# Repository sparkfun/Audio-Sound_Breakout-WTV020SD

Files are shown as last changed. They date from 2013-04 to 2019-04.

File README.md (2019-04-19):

**NOTE:** *This product has been retired from our catalog. For alternatives, try looking at the following products from the [Audio boards](https://www.sparkfun.com/categories/343):*

* [Little Soundie Audio Player](https://www.sparkfun.com/products/14006)
* [Qwiic MP3 Trigger](https://www.sparkfun.com/products/15165)

*If you are looking for more up-to-date info, please check out some of these resources to see how other users are still hacking and improving on this product.*

* *[SparkFun Forum](https://forum.sparkfun.com/)*
* *[IRC Channel](https://www.sparkfun.com/news/263)*

Audio-Sound Breakout
====================

[Audio-Sound Breakout  
*Audio-Sound Breakout (WIG-11125)*](https://www.sparkfun.com/products/11125)

* Firmware was compiled in Arduino 1.0.3.
* Hardware was developed in EAGLE 6.3.0.
* Fritzing part created under 0.7.12.

License Information
-------------------
The hardware design is released under [CC-SA v3 license](http://creativecommons.org/licenses/by-sa/3.0/us/).

The firmware is released under a modified beerware license, allowing for the purchase of any libation, alcoholic or non.

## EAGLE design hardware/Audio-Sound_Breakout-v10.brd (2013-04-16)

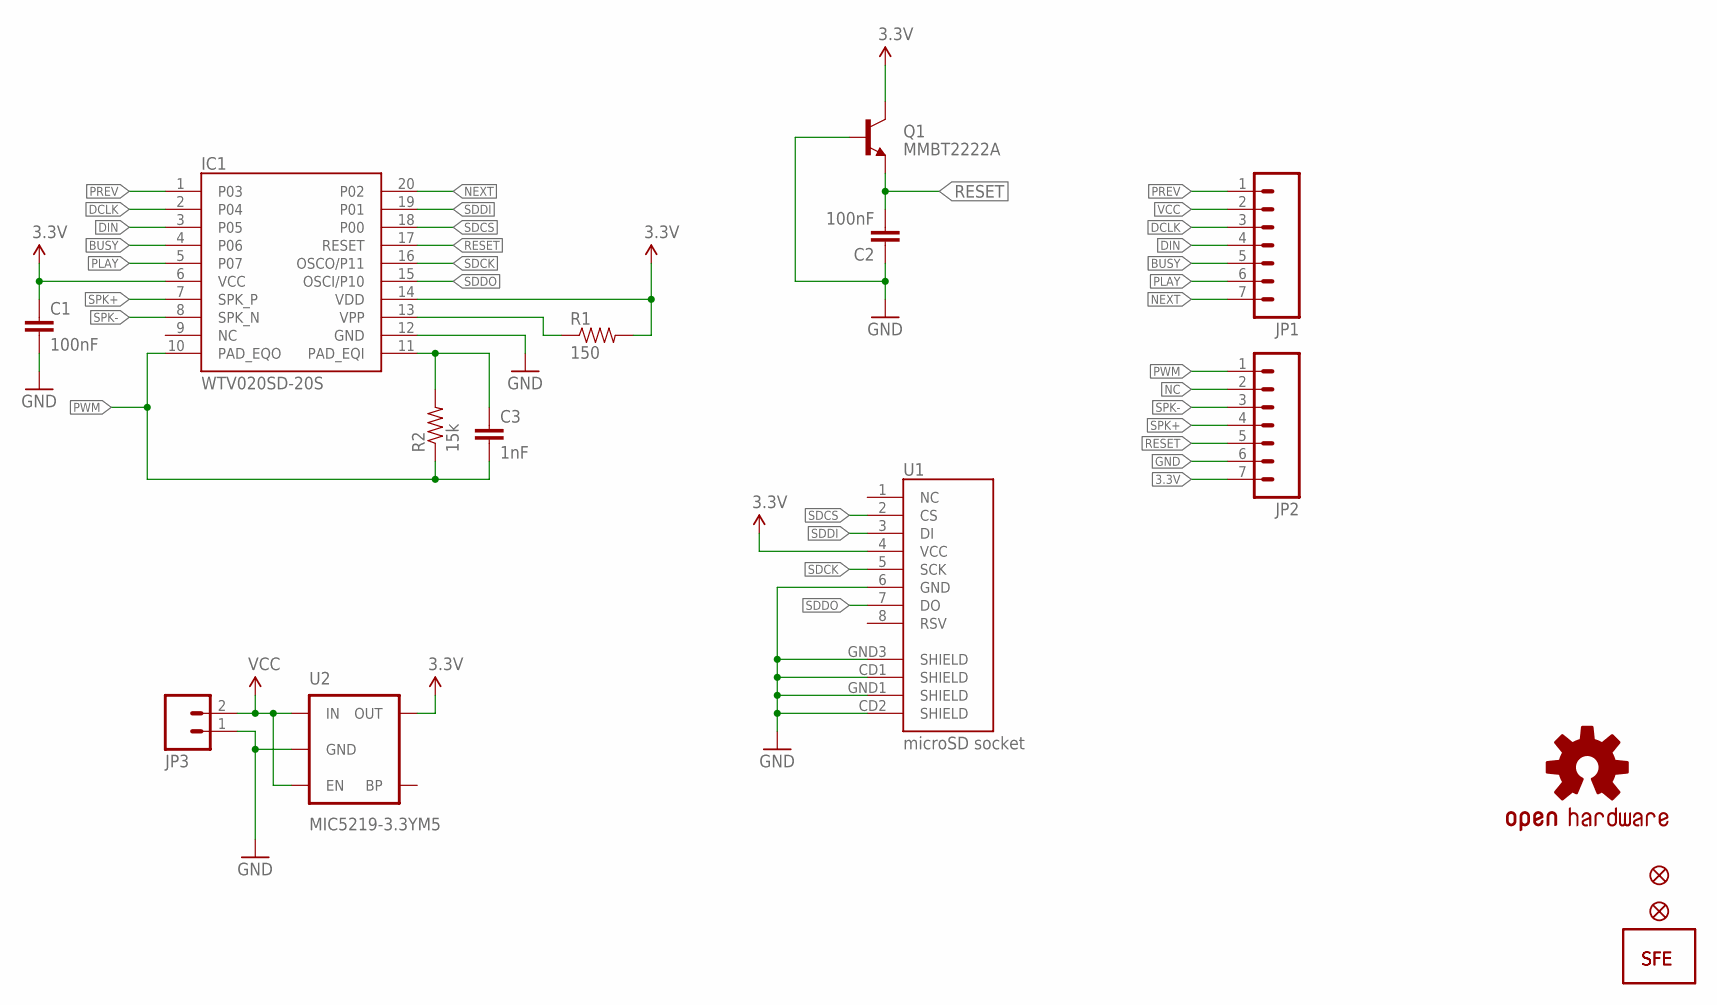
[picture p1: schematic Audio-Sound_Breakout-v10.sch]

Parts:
C1, C2: 100nF; 0402-CAP
C3: 1nF; 0402-CAP
IC1: WTV020SD-20S; SSOP_20
JP1, JP2: M07; 1X07
JP3: M02-JST-2MM-SMT; JST-2-SMD
JP4: LOGO-SFENW2; SFE-NEW-WEB
JP5: LOGO-SFENEW; SFE-NEW-WEBLOGO
JP6, JP7: FIDUCIALUFIDUCIAL; MICRO-FIDUCIAL
Q1: MMBT2222A; SOT23
R1: 150; 0402-RES
R2: 15k; 0402-RES
U1: microSD socket; MICRO-SD-SOCKET-PP
U2: MIC5219-3.3YM5; SOT23-5
U$1: OSHW-LOGOS; OSHW-LOGO-S

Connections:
3.3V: C1.1, IC1.6 (VCC), IC1.14 (VDD), JP2.7, Q1.3 (C), R1.2, U1.4 (VCC), U2.5 (OUT)
BUSY: IC1.4 (P06), JP1.5
DCLK: IC1.2 (P04), JP1.3
DIN: IC1.3 (P05), JP1.4
GND: C1.2, C2.1, IC1.12 (GND), JP2.6, JP3.1 (2), Q1.1 (B), U1.6 (GND), U1.CD1 (SHIELD), U1.CD2 (SHIELD), U1.GND1 (SHIELD), U1.GND3 (SHIELD), U2.2 (GND)
unnamed: IC1.13 (VPP), R1.1
unnamed: C3.1, IC1.11 (PAD_EQI), R2.2
NC: JP2.2
NEXT: IC1.20 (P02), JP1.7
PLAY: IC1.5 (P07), JP1.6
PREV: IC1.1 (P03), JP1.1
PWM: C3.2, IC1.10 (PAD_EQO), JP2.1, R2.1
RESET: C2.2, IC1.17 (RESET), JP2.5, Q1.2 (E)
SDCK: IC1.16 (OSCO/P11), U1.5 (SCK)
SDCS: IC1.18 (P00), U1.2 (CS)
SDDI: IC1.19 (P01), U1.3 (DI)
SDDO: IC1.15 (OSCI/P10), U1.7 (DO)
SPK+: IC1.7 (SPK_P), JP2.4
SPK-: IC1.8 (SPK_N), JP2.3
VCC: JP1.2, JP3.2 (1), U2.1 (IN), U2.3 (EN)

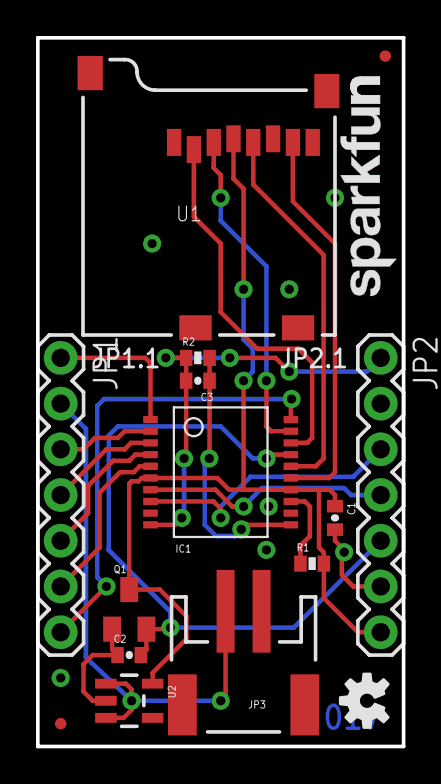
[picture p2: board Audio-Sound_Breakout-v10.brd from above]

Board: 2 copper layers, 20.3 x 39.4 mm, 17 parts (1 on the bottom side), 19 nets.

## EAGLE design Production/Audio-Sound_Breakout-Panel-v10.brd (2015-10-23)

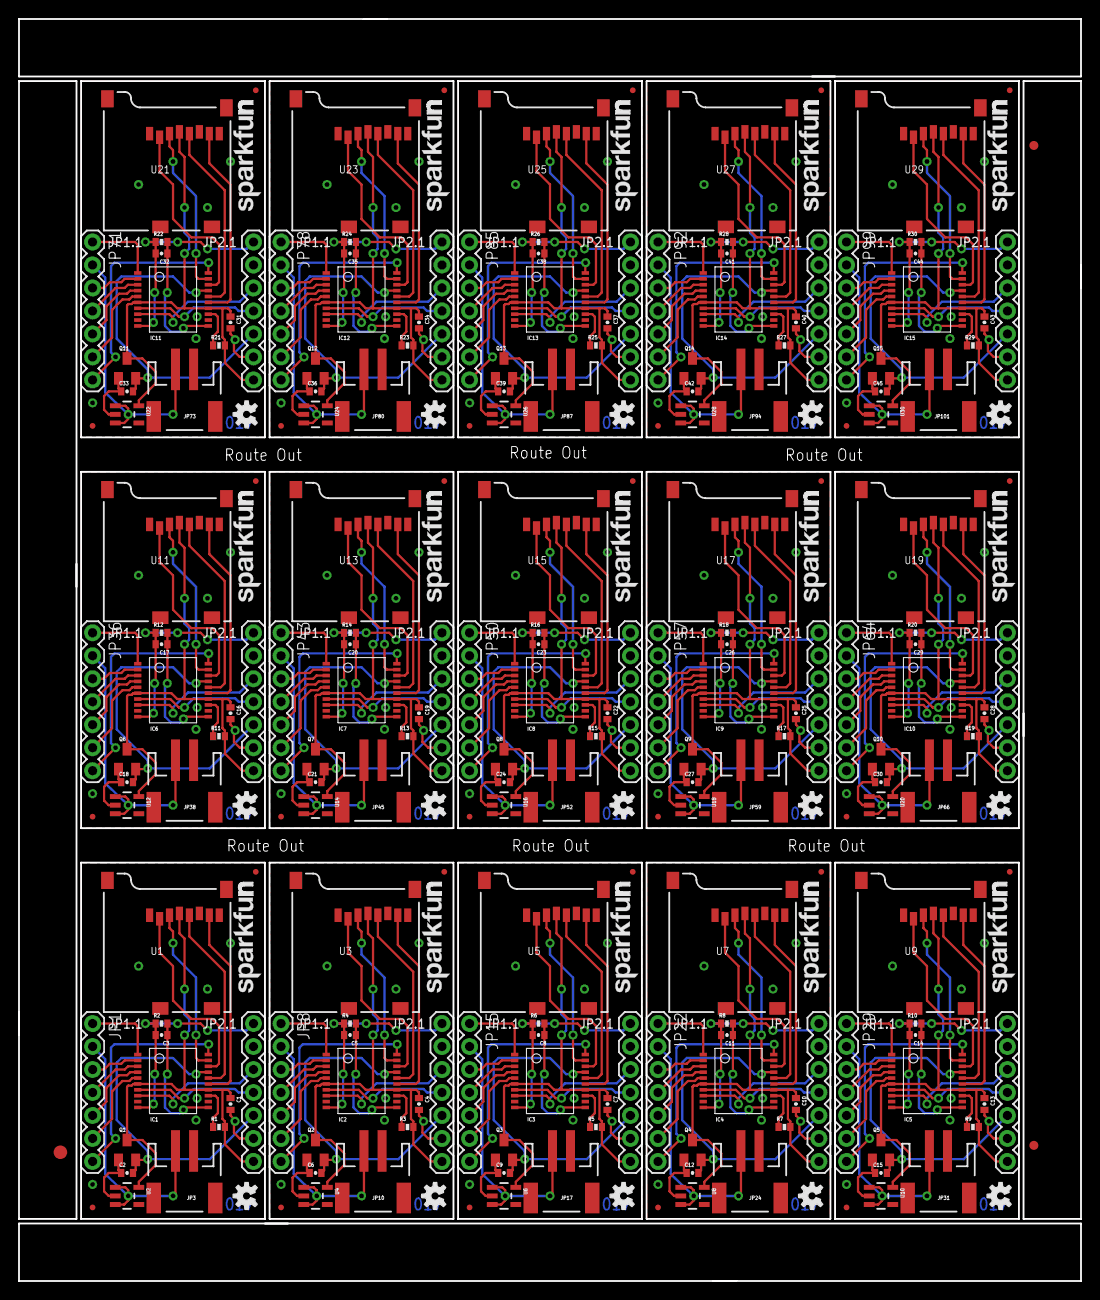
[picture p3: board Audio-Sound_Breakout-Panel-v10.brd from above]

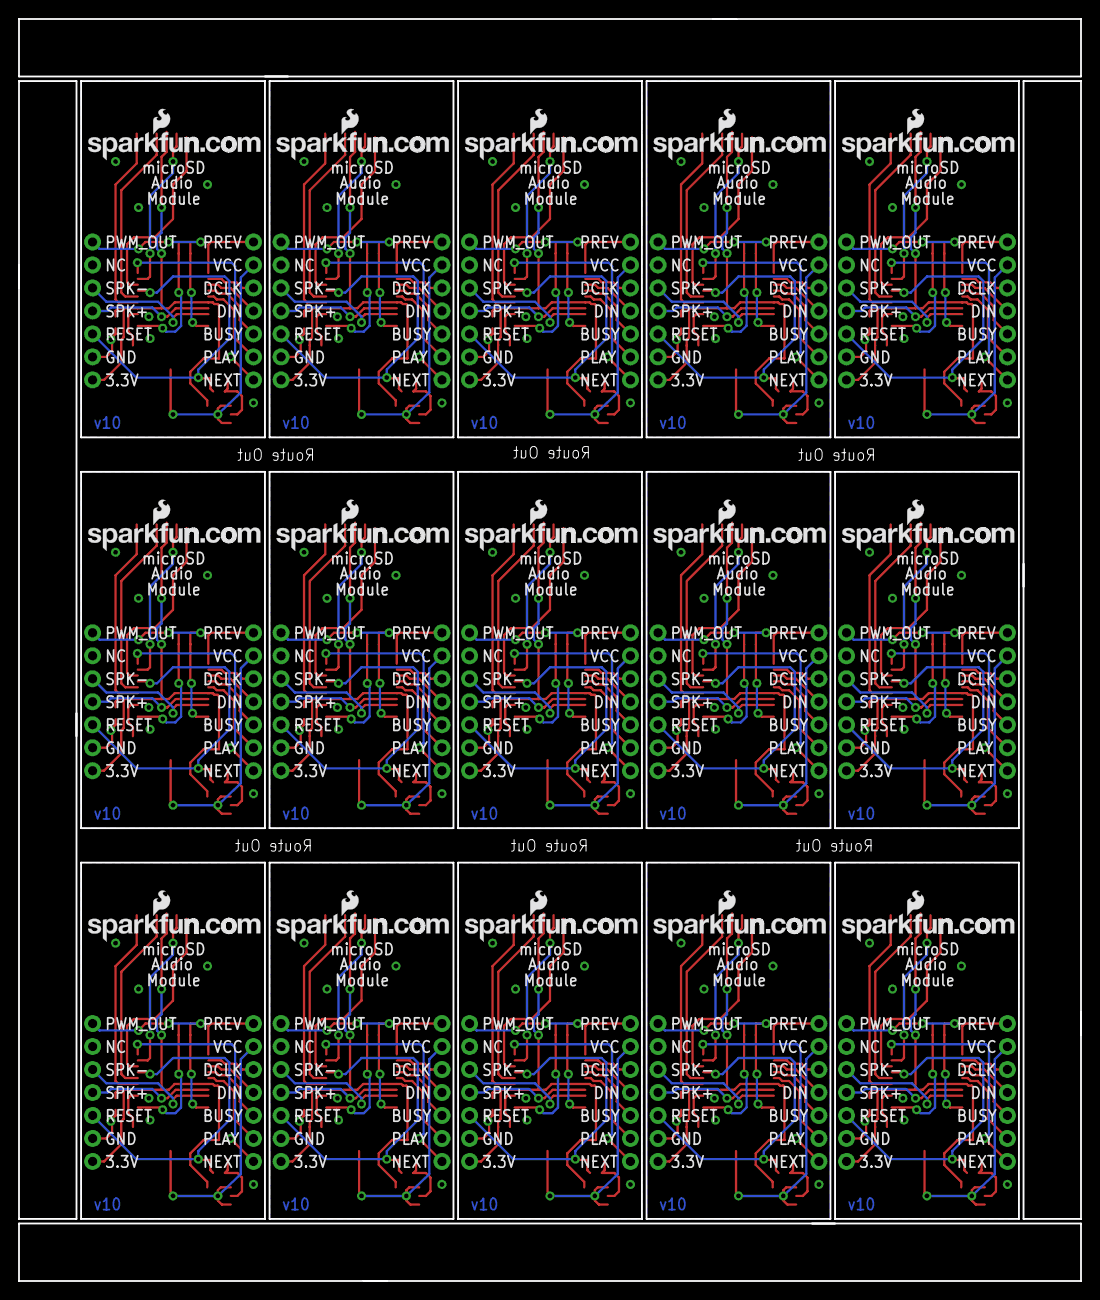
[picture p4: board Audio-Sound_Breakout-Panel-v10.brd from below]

Board: 2 copper layers, 117.3 x 139.4 mm, 258 parts (15 on the bottom side), 285 nets.

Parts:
C1, C2, C4, C6, C7, C9, C10, C12, C13, C15, C16, C18, C19, C21, C22, C24, C25, C27, C28, C30, C31, C33, C34, C36, C37, C39, C40, C42, C43, C45: 100nF; 0402-CAP
C3, C5, C8, C11, C14, C17, C20, C23, C26, C29, C32, C35, C38, C41, C44: 1nF; 0402-CAP
E$1: FIDUCIAL-1.5X3
E$7, E$8: FIDUCIAL-1X2
IC1, IC2, IC3, IC4, IC5, IC6, IC7, IC8, IC9, IC10, IC11, IC12, IC13, IC14, IC15: WTV020SD-20S; SSOP_20
JP1, JP2, JP8, JP9, JP15, JP16, JP22, JP23, JP29, JP30, JP36, JP37, JP43, JP44, JP50, JP51, JP57, JP58, JP64, JP65, JP71, JP72, JP78, JP79, JP85, JP86, JP92, JP93, JP99, JP100: 1X07
JP3, JP10, JP17, JP24, JP31, JP38, JP45, JP52, JP59, JP66, JP73, JP80, JP87, JP94, JP101: JST-2-SMD
JP4, JP11, JP18, JP25, JP32, JP39, JP46, JP53, JP60, JP67, JP74, JP81, JP88, JP95, JP102: LOGO-SFENW2; SFE-NEW-WEB
JP5, JP12, JP19, JP26, JP33, JP40, JP47, JP54, JP61, JP68, JP75, JP82, JP89, JP96, JP103: LOGO-SFENEW; SFE-NEW-WEBLOGO
JP6, JP7, JP13, JP14, JP20, JP21, JP27, JP28, JP34, JP35, JP41, JP42, JP48, JP49, JP55, JP56, JP62, JP63, JP69, JP70, JP76, JP77, JP83, JP84, JP90, JP91, JP97, JP98, JP104, JP105: FIDUCIALUFIDUCIAL; MICRO-FIDUCIAL
Q1, Q2, Q3, Q4, Q5, Q6, Q7, Q8, Q9, Q10, Q11, Q12, Q13, Q14, Q15: MMBT2222A; SOT23
R1, R3, R5, R7, R9, R11, R13, R15, R17, R19, R21, R23, R25, R27, R29: 150; 0402-RES
R2, R4, R6, R8, R10, R12, R14, R16, R18, R20, R22, R24, R26, R28, R30: 15k; 0402-RES
U1, U3, U5, U7, U9, U11, U13, U15, U17, U19, U21, U23, U25, U27, U29: microSD socket; MICRO-SD-SOCKET-PP
U2, U4, U6, U8, U10, U12, U14, U16, U18, U20, U22, U24, U26, U28, U30: MIC5219-3.3YM5; SOT23-5
U$1, U$2, U$3, U$4, U$5, U$6, U$7, U$8, U$9, U$10, U$11, U$12, U$13, U$14, U$15: OSHW-LOGOS; OSHW-LOGO-S

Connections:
3.3V: C1.1, IC1.6, IC1.14, JP2.7, Q1.3, R1.2, U1.4, U2.5
3.3V1: C4.1, IC2.6, IC2.14, JP9.7, Q2.3, R3.2, U3.4, U4.5
3.3V2: C7.1, IC3.6, IC3.14, JP16.7, Q3.3, R5.2, U5.4, U6.5
3.3V3: C10.1, IC4.6, IC4.14, JP23.7, Q4.3, R7.2, U7.4, U8.5
3.3V4: C13.1, IC5.6, IC5.14, JP30.7, Q5.3, R9.2, U9.4, U10.5
3.3V5: C16.1, IC6.6, IC6.14, JP37.7, Q6.3, R11.2, U11.4, U12.5
3.3V6: C19.1, IC7.6, IC7.14, JP44.7, Q7.3, R13.2, U13.4, U14.5
3.3V7: C22.1, IC8.6, IC8.14, JP51.7, Q8.3, R15.2, U15.4, U16.5
3.3V8: C25.1, IC9.6, IC9.14, JP58.7, Q9.3, R17.2, U17.4, U18.5
3.3V9: C28.1, IC10.6, IC10.14, JP65.7, Q10.3, R19.2, U19.4, U20.5
3.3V10: C31.1, IC11.6, IC11.14, JP72.7, Q11.3, R21.2, U21.4, U22.5
3.3V11: C34.1, IC12.6, IC12.14, JP79.7, Q12.3, R23.2, U23.4, U24.5
3.3V12: C37.1, IC13.6, IC13.14, JP86.7, Q13.3, R25.2, U25.4, U26.5
3.3V13: C40.1, IC14.6, IC14.14, JP93.7, Q14.3, R27.2, U27.4, U28.5
3.3V14: C43.1, IC15.6, IC15.14, JP100.7, Q15.3, R29.2, U29.4, U30.5
BUSY: IC1.4, JP1.5
BUSY1: IC2.4, JP8.5
BUSY2: IC3.4, JP15.5
BUSY3: IC4.4, JP22.5
BUSY4: IC5.4, JP29.5
BUSY5: IC6.4, JP36.5
BUSY6: IC7.4, JP43.5
BUSY7: IC8.4, JP50.5
BUSY8: IC9.4, JP57.5
BUSY9: IC10.4, JP64.5
BUSY10: IC11.4, JP71.5
BUSY11: IC12.4, JP78.5
BUSY12: IC13.4, JP85.5
BUSY13: IC14.4, JP92.5
BUSY14: IC15.4, JP99.5
DCLK: IC1.2, JP1.3
DCLK1: IC2.2, JP8.3
DCLK2: IC3.2, JP15.3
DCLK3: IC4.2, JP22.3
DCLK4: IC5.2, JP29.3
DCLK5: IC6.2, JP36.3
DCLK6: IC7.2, JP43.3
DCLK7: IC8.2, JP50.3
DCLK8: IC9.2, JP57.3
DCLK9: IC10.2, JP64.3
DCLK10: IC11.2, JP71.3
DCLK11: IC12.2, JP78.3
DCLK12: IC13.2, JP85.3
DCLK13: IC14.2, JP92.3
DCLK14: IC15.2, JP99.3
DIN: IC1.3, JP1.4
DIN1: IC2.3, JP8.4
DIN2: IC3.3, JP15.4
DIN3: IC4.3, JP22.4
DIN4: IC5.3, JP29.4
DIN5: IC6.3, JP36.4
DIN6: IC7.3, JP43.4
DIN7: IC8.3, JP50.4
DIN8: IC9.3, JP57.4
DIN9: IC10.3, JP64.4
DIN10: IC11.3, JP71.4
DIN11: IC12.3, JP78.4
DIN12: IC13.3, JP85.4
DIN13: IC14.3, JP92.4
DIN14: IC15.3, JP99.4
GND: C1.2, C2.1, IC1.12, JP2.6, JP3.1, Q1.1, U1.6, U1.CD1, U1.CD2, U1.GND1, U1.GND3, U2.2
GND1: C4.2, C6.1, IC2.12, JP9.6, JP10.1, Q2.1, U3.6, U3.CD1, U3.CD2, U3.GND1, U3.GND3, U4.2
GND2: C7.2, C9.1, IC3.12, JP16.6, JP17.1, Q3.1, U5.6, U5.CD1, U5.CD2, U5.GND1, U5.GND3, U6.2
GND3: C10.2, C12.1, IC4.12, JP23.6, JP24.1, Q4.1, U7.6, U7.CD1, U7.CD2, U7.GND1, U7.GND3, U8.2
GND4: C13.2, C15.1, IC5.12, JP30.6, JP31.1, Q5.1, U9.6, U9.CD1, U9.CD2, U9.GND1, U9.GND3, U10.2
GND5: C16.2, C18.1, IC6.12, JP37.6, JP38.1, Q6.1, U11.6, U11.CD1, U11.CD2, U11.GND1, U11.GND3, U12.2
GND6: C19.2, C21.1, IC7.12, JP44.6, JP45.1, Q7.1, U13.6, U13.CD1, U13.CD2, U13.GND1, U13.GND3, U14.2
GND7: C22.2, C24.1, IC8.12, JP51.6, JP52.1, Q8.1, U15.6, U15.CD1, U15.CD2, U15.GND1, U15.GND3, U16.2
GND8: C25.2, C27.1, IC9.12, JP58.6, JP59.1, Q9.1, U17.6, U17.CD1, U17.CD2, U17.GND1, U17.GND3, U18.2
GND9: C28.2, C30.1, IC10.12, JP65.6, JP66.1, Q10.1, U19.6, U19.CD1, U19.CD2, U19.GND1, U19.GND3, U20.2
GND10: C31.2, C33.1, IC11.12, JP72.6, JP73.1, Q11.1, U21.6, U21.CD1, U21.CD2, U21.GND1, U21.GND3, U22.2
GND11: C34.2, C36.1, IC12.12, JP79.6, JP80.1, Q12.1, U23.6, U23.CD1, U23.CD2, U23.GND1, U23.GND3, U24.2
GND12: C37.2, C39.1, IC13.12, JP86.6, JP87.1, Q13.1, U25.6, U25.CD1, U25.CD2, U25.GND1, U25.GND3, U26.2
GND13: C40.2, C42.1, IC14.12, JP93.6, JP94.1, Q14.1, U27.6, U27.CD1, U27.CD2, U27.GND1, U27.GND3, U28.2
GND14: C43.2, C45.1, IC15.12, JP100.6, JP101.1, Q15.1, U29.6, U29.CD1, U29.CD2, U29.GND1, U29.GND3, U30.2
unnamed: IC1.13, R1.1
unnamed: C3.1, IC1.11, R2.2
unnamed: IC2.13, R3.1
unnamed: C5.1, IC2.11, R4.2
unnamed: IC3.13, R5.1
unnamed: C8.1, IC3.11, R6.2
unnamed: IC4.13, R7.1
unnamed: C11.1, IC4.11, R8.2
unnamed: IC5.13, R9.1
unnamed: C14.1, IC5.11, R10.2
unnamed: IC6.13, R11.1
unnamed: C17.1, IC6.11, R12.2
unnamed: IC7.13, R13.1
unnamed: C20.1, IC7.11, R14.2
unnamed: IC8.13, R15.1
unnamed: C23.1, IC8.11, R16.2
unnamed: IC9.13, R17.1
unnamed: C26.1, IC9.11, R18.2
unnamed: IC10.13, R19.1
unnamed: C29.1, IC10.11, R20.2
unnamed: IC11.13, R21.1
unnamed: C32.1, IC11.11, R22.2
unnamed: IC12.13, R23.1
unnamed: C35.1, IC12.11, R24.2
unnamed: IC13.13, R25.1
unnamed: C38.1, IC13.11, R26.2
unnamed: IC14.13, R27.1
unnamed: C41.1, IC14.11, R28.2
unnamed: IC15.13, R29.1
unnamed: C44.1, IC15.11, R30.2
NEXT: IC1.20, JP1.7
NEXT1: IC2.20, JP8.7
NEXT2: IC3.20, JP15.7
NEXT3: IC4.20, JP22.7
NEXT4: IC5.20, JP29.7
NEXT5: IC6.20, JP36.7
NEXT6: IC7.20, JP43.7
NEXT7: IC8.20, JP50.7
NEXT8: IC9.20, JP57.7
NEXT9: IC10.20, JP64.7
NEXT10: IC11.20, JP71.7
NEXT11: IC12.20, JP78.7
NEXT12: IC13.20, JP85.7
NEXT13: IC14.20, JP92.7
NEXT14: IC15.20, JP99.7
PLAY: IC1.5, JP1.6
PLAY1: IC2.5, JP8.6
PLAY2: IC3.5, JP15.6
PLAY3: IC4.5, JP22.6
PLAY4: IC5.5, JP29.6
PLAY5: IC6.5, JP36.6
PLAY6: IC7.5, JP43.6
PLAY7: IC8.5, JP50.6
PLAY8: IC9.5, JP57.6
PLAY9: IC10.5, JP64.6
PLAY10: IC11.5, JP71.6
PLAY11: IC12.5, JP78.6
PLAY12: IC13.5, JP85.6
PLAY13: IC14.5, JP92.6
PLAY14: IC15.5, JP99.6
PREV: IC1.1, JP1.1
PREV1: IC2.1, JP8.1
PREV2: IC3.1, JP15.1
PREV3: IC4.1, JP22.1
PREV4: IC5.1, JP29.1
PREV5: IC6.1, JP36.1
PREV6: IC7.1, JP43.1
PREV7: IC8.1, JP50.1
PREV8: IC9.1, JP57.1
PREV9: IC10.1, JP64.1
PREV10: IC11.1, JP71.1
PREV11: IC12.1, JP78.1
PREV12: IC13.1, JP85.1
PREV13: IC14.1, JP92.1
PREV14: IC15.1, JP99.1
PWM: C3.2, IC1.10, JP2.1, R2.1
PWM1: C5.2, IC2.10, JP9.1, R4.1
PWM2: C8.2, IC3.10, JP16.1, R6.1
PWM3: C11.2, IC4.10, JP23.1, R8.1
PWM4: C14.2, IC5.10, JP30.1, R10.1
PWM5: C17.2, IC6.10, JP37.1, R12.1
PWM6: C20.2, IC7.10, JP44.1, R14.1
PWM7: C23.2, IC8.10, JP51.1, R16.1
PWM8: C26.2, IC9.10, JP58.1, R18.1
PWM9: C29.2, IC10.10, JP65.1, R20.1
PWM10: C32.2, IC11.10, JP72.1, R22.1
PWM11: C35.2, IC12.10, JP79.1, R24.1
PWM12: C38.2, IC13.10, JP86.1, R26.1
PWM13: C41.2, IC14.10, JP93.1, R28.1
PWM14: C44.2, IC15.10, JP100.1, R30.1
RESET: C2.2, IC1.17, JP2.5, Q1.2
RESET1: C6.2, IC2.17, JP9.5, Q2.2
RESET2: C9.2, IC3.17, JP16.5, Q3.2
RESET3: C12.2, IC4.17, JP23.5, Q4.2
RESET4: C15.2, IC5.17, JP30.5, Q5.2
RESET5: C18.2, IC6.17, JP37.5, Q6.2
RESET6: C21.2, IC7.17, JP44.5, Q7.2
RESET7: C24.2, IC8.17, JP51.5, Q8.2
RESET8: C27.2, IC9.17, JP58.5, Q9.2
RESET9: C30.2, IC10.17, JP65.5, Q10.2
RESET10: C33.2, IC11.17, JP72.5, Q11.2
RESET11: C36.2, IC12.17, JP79.5, Q12.2
RESET12: C39.2, IC13.17, JP86.5, Q13.2
RESET13: C42.2, IC14.17, JP93.5, Q14.2
RESET14: C45.2, IC15.17, JP100.5, Q15.2
SDCK: IC1.16, U1.5
SDCK1: IC2.16, U3.5
SDCK2: IC3.16, U5.5
SDCK3: IC4.16, U7.5
SDCK4: IC5.16, U9.5
SDCK5: IC6.16, U11.5
SDCK6: IC7.16, U13.5
SDCK7: IC8.16, U15.5
SDCK8: IC9.16, U17.5
SDCK9: IC10.16, U19.5
SDCK10: IC11.16, U21.5
SDCK11: IC12.16, U23.5
SDCK12: IC13.16, U25.5
SDCK13: IC14.16, U27.5
SDCK14: IC15.16, U29.5
SDCS: IC1.18, U1.2
SDCS1: IC2.18, U3.2
SDCS2: IC3.18, U5.2
SDCS3: IC4.18, U7.2
SDCS4: IC5.18, U9.2
SDCS5: IC6.18, U11.2
SDCS6: IC7.18, U13.2
SDCS7: IC8.18, U15.2
SDCS8: IC9.18, U17.2
SDCS9: IC10.18, U19.2
SDCS10: IC11.18, U21.2
SDCS11: IC12.18, U23.2
SDCS12: IC13.18, U25.2
SDCS13: IC14.18, U27.2
SDCS14: IC15.18, U29.2
SDDI: IC1.19, U1.3
SDDI1: IC2.19, U3.3
SDDI2: IC3.19, U5.3
SDDI3: IC4.19, U7.3
SDDI4: IC5.19, U9.3
SDDI5: IC6.19, U11.3
SDDI6: IC7.19, U13.3
SDDI7: IC8.19, U15.3
SDDI8: IC9.19, U17.3
SDDI9: IC10.19, U19.3
SDDI10: IC11.19, U21.3
SDDI11: IC12.19, U23.3
SDDI12: IC13.19, U25.3
SDDI13: IC14.19, U27.3
SDDI14: IC15.19, U29.3
SDDO: IC1.15, U1.7
SDDO1: IC2.15, U3.7
SDDO2: IC3.15, U5.7
SDDO3: IC4.15, U7.7
SDDO4: IC5.15, U9.7
SDDO5: IC6.15, U11.7
SDDO6: IC7.15, U13.7
SDDO7: IC8.15, U15.7
SDDO8: IC9.15, U17.7
SDDO9: IC10.15, U19.7
SDDO10: IC11.15, U21.7
SDDO11: IC12.15, U23.7
SDDO12: IC13.15, U25.7
SDDO13: IC14.15, U27.7
SDDO14: IC15.15, U29.7
SPK+: IC1.7, JP2.4
SPK+1: IC2.7, JP9.4
SPK+2: IC3.7, JP16.4
SPK+3: IC4.7, JP23.4
SPK+4: IC5.7, JP30.4
SPK+5: IC6.7, JP37.4
SPK+6: IC7.7, JP44.4
SPK+7: IC8.7, JP51.4
SPK+8: IC9.7, JP58.4
SPK+9: IC10.7, JP65.4
SPK+10: IC11.7, JP72.4
SPK+11: IC12.7, JP79.4
SPK+12: IC13.7, JP86.4
SPK+13: IC14.7, JP93.4
SPK+14: IC15.7, JP100.4
SPK-: IC1.8, JP2.3
SPK-1: IC2.8, JP9.3
SPK-2: IC3.8, JP16.3
SPK-3: IC4.8, JP23.3
SPK-4: IC5.8, JP30.3
SPK-5: IC6.8, JP37.3
SPK-6: IC7.8, JP44.3
SPK-7: IC8.8, JP51.3
SPK-8: IC9.8, JP58.3
SPK-9: IC10.8, JP65.3
SPK-10: IC11.8, JP72.3
SPK-11: IC12.8, JP79.3
SPK-12: IC13.8, JP86.3
SPK-13: IC14.8, JP93.3
SPK-14: IC15.8, JP100.3
VCC: JP1.2, JP3.2, U2.1, U2.3
VCC1: JP8.2, JP10.2, U4.1, U4.3
VCC2: JP15.2, JP17.2, U6.1, U6.3
VCC3: JP22.2, JP24.2, U8.1, U8.3
VCC4: JP29.2, JP31.2, U10.1, U10.3
VCC5: JP36.2, JP38.2, U12.1, U12.3
VCC6: JP43.2, JP45.2, U14.1, U14.3
VCC7: JP50.2, JP52.2, U16.1, U16.3
VCC8: JP57.2, JP59.2, U18.1, U18.3
VCC9: JP64.2, JP66.2, U20.1, U20.3
VCC10: JP71.2, JP73.2, U22.1, U22.3
VCC11: JP78.2, JP80.2, U24.1, U24.3
VCC12: JP85.2, JP87.2, U26.1, U26.3
VCC13: JP92.2, JP94.2, U28.1, U28.3
VCC14: JP99.2, JP101.2, U30.1, U30.3

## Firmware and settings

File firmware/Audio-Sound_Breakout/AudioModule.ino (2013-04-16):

//-----------------------------------------------------------------------------
// Pin definitions
#define RESET 9    // Pull this low for at least 6ms to reset the audio module. 
                   //  Allow at least 300ms after reset before interacting with
                   //  the chip.
#define NEXT  8    // Play the next track. If you wish to advance the pointer
                   //  but not play the next track, you must immediately follow
                   //  a toggle of this pin with a toggle of the PLAY pin. Note
                   //  that the pointer for pin operations is different to the
                   //  pointer for the 2-wire serial controller. See above for
                   //  more instructions.
#define PREV  7    // Just like NEXT, but backwards.
#define PLAY  6    // Play, or stop, the current track. This stops playback, so
                   //  upon the next toggle of the PLAY pin, playback will
                   //  begin from the start of the current track. It does NOT
                   //  pause playback.
#define BUSY  5    // HIGH during playback.
#define DOUT  4    // Data input from a microcontroller.
#define DCLK  3    // Data clock from a microcontroller.

// Opcode definitions- the 2-wire serial (which is NOT I2C- it is close to SPI
//  without a CS or MISO, but the Arduino can't clock data slowly enough to
//  suit the widget when using the internal SPI peripheral).
#define OPCODE_PLAY_PAUSE  0xFFFE   // Play a track, or pause the current
                                    //  playback. Note that this requires that
                                    //  you first send a number from 0-511 to
                                    //  the module to indicate which track you
                                    //  wish to play back- simply sending the
                                    //  PLAY_PAUSE opcode has no effect other
                                    //  than pausing playback.
#define OPCODE_STOP        0xFFFF   // Stops the current playback. Subsequent
                                    //  toggling of the PLAY pin will start
                                    //  playback as though no previous track
                                    //  were playing.
#define OPCODE_VOL         0xFFF0   // Set the volume. 0xFFF0 is muted, 0xFFF7
                                    //  is max. Defaults to max on startup.

byte file = 0;   // This is a file counter used to internally track the pointer
                 //  for playback. There is no way to read the internal pointer
                 //  and find out which track will play if you simply strobe the
                 //  PLAY pin, or which track you'll be moving to if you strobe
                 //  NEXT or PREV.

void setup()
{
  Serial.begin(57600);
  pinSetup();
  resetModule();
}

void loop() 
{
  if (Serial.available() > 0)
  {
    byte command = Serial.read();
    switch(command)
    {
      case 'p':
        sendCommand((unsigned int) file);
        sendCommand(OPCODE_PLAY_PAUSE);
        break;
      case 's':
        sendCommand(OPCODE_STOP);
        break;
      case 'n':
        if (file++ == 11) file = 0;
        digitalWrite(NEXT, LOW);
        delay(10);
        digitalWrite(NEXT, HIGH);
        break;
      case 'b':
        if (file-- == 255) file = 10;
        digitalWrite(PREV, LOW);
        delay(10);
        digitalWrite(PREV, HIGH);
        break;
      case '+':
        if (file++ == 11) file = 0;
        digitalWrite(NEXT, LOW);
        delay(10);
        digitalWrite(NEXT, HIGH);
        while(digitalRead(BUSY) == HIGH);
        digitalWrite(PLAY, LOW);
        delay(10);
        digitalWrite(PLAY, HIGH);
        break;
      case '-':
        if (file-- == 255) file = 10;
        digitalWrite(PREV, LOW);
        delay(10);
        digitalWrite(PREV, HIGH);
        while(digitalRead(BUSY) == HIGH);
        digitalWrite(PLAY, LOW);
        delay(10);
        digitalWrite(PLAY, HIGH);
        break;
      case 't':
        digitalWrite(PLAY, LOW);
        delay(10);
        digitalWrite(PLAY, HIGH);
        break;
      case 'x':
        sendCommand(OPCODE_PLAY_PAUSE);
        break;
    } 
  }
}

void pinSetup()
{
  pinMode(RESET, OUTPUT);
  digitalWrite(RESET, LOW);
  pinMode(NEXT, OUTPUT);
  digitalWrite(NEXT, HIGH);
  pinMode(PREV, OUTPUT);
  digitalWrite(PREV, HIGH);
  pinMode(PLAY, OUTPUT);
  digitalWrite(PLAY, HIGH);
  
  pinMode(DOUT, OUTPUT);
  digitalWrite(DOUT, HIGH);
  pinMode(DCLK, OUTPUT);
  digitalWrite(DOUT, HIGH);
  
  pinMode(BUSY, INPUT);
}

void resetModule()
{
  digitalWrite(RESET, LOW);
  delay(100);
  digitalWrite(RESET, HIGH);
  delay(500);
}

void sendCommand(unsigned int command)
{
  digitalWrite(DCLK, LOW);
  delayMicroseconds(1900);
  for (byte i = 0; i < 16; i++)
  {
    delayMicroseconds(100);
    digitalWrite(DCLK, LOW);
    digitalWrite(DOUT, LOW);
    if ((command & 0x8000) != 0)
    {
      digitalWrite(DOUT, HIGH);
    }
    delayMicroseconds(100);
    digitalWrite(DCLK, HIGH);
    command = command<<1;
  }
}
      
    

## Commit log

2013-04-16 Initial commit of production files.
    [Audio-Sound_Breakout-v10.brd, Audio-Sound_Breakout-v10.sch]
2015-10-23 recreated panel v10
    [Audio-Sound_Breakout-Panel-v10.brd]

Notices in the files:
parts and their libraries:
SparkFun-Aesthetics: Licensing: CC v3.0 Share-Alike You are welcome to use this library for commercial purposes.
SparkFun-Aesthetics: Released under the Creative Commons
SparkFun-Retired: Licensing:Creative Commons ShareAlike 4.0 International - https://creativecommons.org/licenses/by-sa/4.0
